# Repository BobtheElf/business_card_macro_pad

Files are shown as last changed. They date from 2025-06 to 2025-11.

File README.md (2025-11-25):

# Business Card Macro Pad
As an electrical engineer, I wanted to design a business card that can also help the people with whom I am networking. This business card doubles as an RP2040 macro pad, which can be programmed to include any custom key bindings. Special thanks to Robert Feranec at FEDEVEL which this board makes heavy modifications to. His playlist where I learned to make this is here: <https://www.youtube.com/playlist?list=PLXvLToQzgzdftro2qK5In8p6ExsDFdpzw>

In addition, this repository includes the Gerber files, BOM, PnP, and 3D shell files to manufacture this board. Firmware exists in the Software directory, where you can use qmk to flash the board and via to program it once it is flashed. This is what it looks like fully built:

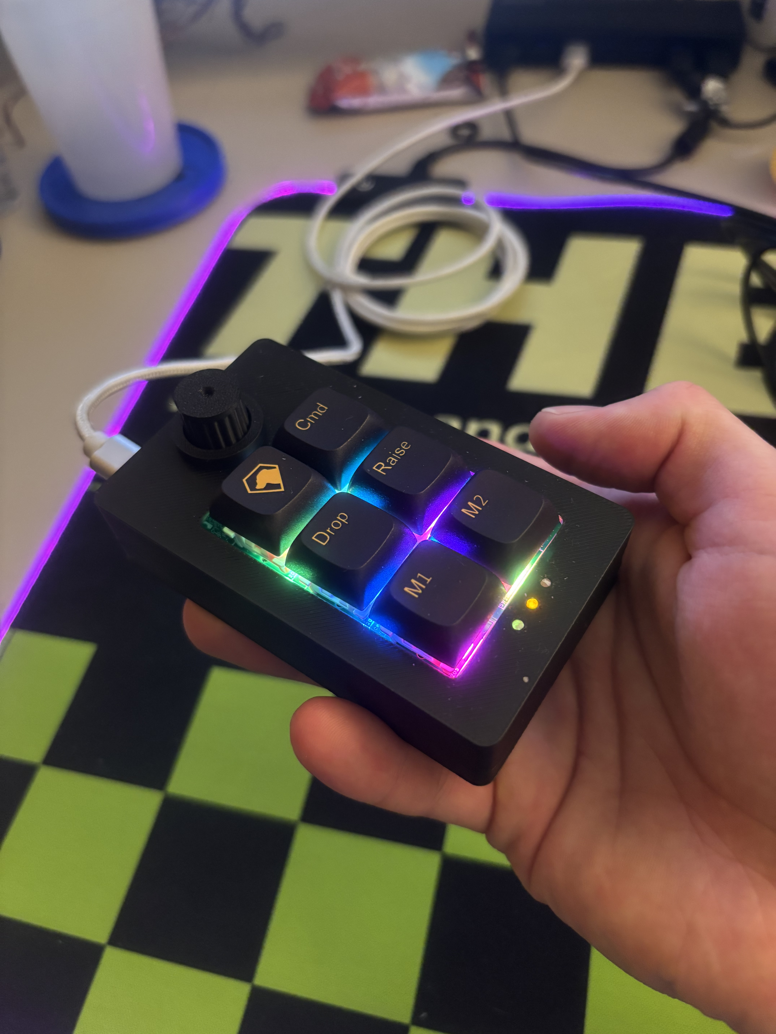
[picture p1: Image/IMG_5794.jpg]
1 encoder, 6 key macro pad with black, 3D printed case and RGB underglow underneath each key switch


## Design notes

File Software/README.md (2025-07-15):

# Software
The two documents you will need to ensure the ability to use Via are the qmk-compiled default firmware ```bcmp.uf2``` as well as the ```via.json``` file which gives Via the correct key mappings and layouts to interface with the qmk-compiled code. Note that Via may be painfully slow or unresponsive when authorizing this keyboard, but if you check the Settings tab or inspect the page or check the console, you can see that these are the correct steps. 
## Flashing the board with default firmware
1. Set the board to bootloader mode. If the board is brand new and unprogrammed, then it will automatically be in bootloader mode upon plugin, however, if there is already code, then press the *BOOT* button as the board is being plugged in. After releasing the *BOOT* button, the board will be in bootloader mode and appear as a drive called ```RPI-RP2```.
2. Copy the ```bcmp.uf2``` file into the ```RPI-RP2``` drive. After this, the board will disconnect as a drive and reappear as a keyboard, complete with the default firmware.
## Programming with Via
1. Visit ```https://usevia.app/``` on your browser.
2. Go to the Settings tab and toggle the "Show Design tab" option on. There should be a new menu option appear, and this is the Design tab.
3. Go to the Design tab and click the option to "Load Draft Definition". Find the ```via.json``` file and load this as the draft definition. The entry "Jaron's Business Card Macro Pad" should appear under the "Draft Definitions" section.
4. Go to the Configure tab and click the "Authorize device +" button. Then authorize "Jaron's Business Card Macro Pad".

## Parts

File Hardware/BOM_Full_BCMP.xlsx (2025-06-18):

No. | Quantity | Comment | Designator | Footprint | Value | Manufacturer Part | Manufacturer | Supplier Part | Supplier | Layer
1 | 5 | 2.2uF | C101,C106,C107,C108,C201 | C0402 | 2.2uF | CL05A225MQ5NSNC | SAMSUNG(三星) | C12530 | LCSC | B
2 | 4 | 1uF | C102,C103,C119,C120 | C0402 | 1uF | CL05A105KA5NQNC | SAMSUNG(三星) | C52923 | LCSC | B
3 | 18 | 100nF | C104,C105,C109,C110,C111,C112,C113,C114,C115,C125,C126,C127,C210,C211,C212,C213,C214,C215 | C0402 | 100nF | CL05B104KO5NNNC | SAMSUNG(三星) | C1525 | LCSC | B
4 | 1 | 47uF | C116 | C1206 | 47uF | CL31A476MPHNNNE | SAMSUNG(三星) | C96123 | LCSC | B
5 | 2 | 15pF | C123,C124 | C0402 | 15pF | CL05C150JB5NNNC | SAMSUNG(三星) | C86285 | LCSC | B
6 | 2 | 10nF | C203,C205 | C0402 | 10nF | CL05B103KB5NNNC | SAMSUNG(三星) | C15195 | LCSC | B
7 | 4 | GG0402052R542P | D101,D102,D103,D104 | D0402-BI |  | GG0402052R542P | Kyocera AVX | C1973257 | LCSC | B
8 | 7 | CD4148WSP | D201,D202,D203,D204,D205,D206,D210 | D0805-RD |  | CD4148WSP | LIZ(丽智电子) | C109001 | LCSC | B
9 | 1 | PEC12R-4120F-S0012 | ENC201 | SW-TH_PEC12R-4120F-S0012 |  | PEC12R-4120F-S0012 | BOURNS | C143801 | LCSC | T
10 | 1 | TYPE-C 16PIN 2MD(073) | J101 | USB-C-SMD_TYPE-C-6PIN-2MD-073 |  | TYPE-C 16PIN 2MD(073) | SHOU HAN(首韩) | C2765186 | LCSC | B
11 | 6 | CPG151101S11-16 | J201,J202,J203,J204,J205,J206 | SMD_KEYBOARD-SW |  | CPG151101S11-16 | Kailh(凯华) | C5156480 | LCSC | B
12 | 1 | NH-B1010RGBT-HF | LED101 | LED-ARRAY-SMD_4P-L1.0-W1.0-TR_NH-B1010RGBT |  | NH-B1010RGBT-HF | 国星光电 | C2874113 | LCSC | T
13 | 1 | KT-0805G | LED102 | LED0805-R-RD |  | KT-0805G | KENTO | C2297 | LCSC | T
14 | 1 | KT-0805Y | LED103 | LED0805-R-RD |  | KT-0805Y | KENTO | C2296 | LCSC | T
15 | 6 | SK6812MINI-E | LED201,LED202,LED203,LED204,LED205,LED206 | LED-SMD_L3.2-W2.8-LS5.9_SK6812MINI-E |  | SK6812MINI-E | 欧思科光电 | C5149201 | LCSC | B
16 | 4 | STANDOFF_M2.5X3.2MM | MH201,MH202,MH203,MH204 | STANDOFF_M2.5X3.5MM_JO_v1.0 |  |  | WURTH ELEKTRONIK | 46AJ4353 | FARNELL | T
17 | 7 | 1kΩ | R101,R102,R103,R104,R105,R121,R124 | R0402 | 1kΩ | 0402WGF1001TCE | UNI-ROYAL(厚声) | C11702 | LCSC | B
18 | 1 | 200Ω | R106 | R0402 | 200Ω | 0402WGF2000TCE | UNI-ROYAL(厚声) | C25087 | LCSC | B
19 | 1 | 100mΩ | R107 | R1206 | 100mΩ | 1206W4F100LT5E | UNI-ROYAL(厚声) | C25334 | LCSC | B
20 | 7 | 27Ω | R108,R109,R110,R111,R112,R118,R125 | R0402 | 27Ω | 0402WGF270JTCE | UNI-ROYAL(厚声) | C25100 | LCSC | B
21 | 2 | 5.1kΩ | R113,R116 | R0402 | 5.1kΩ | 0402WGF5101TCE | UNI-ROYAL(厚声) | C25905 | LCSC | B
22 | 3 | 0Ω | R114,R115,R117 | R0402 | 0Ω | 0402WGF0000TCE | UNI-ROYAL(厚声) | C17168 | LCSC | B
23 | 5 | 10kΩ | R123,R201,R202,R205,R207 | R0402 | 10kΩ | 0402WGF1002TCE | UNI-ROYAL(厚声) | C25744 | LCSC | B
24 | 2 | TS-1187A-B-A-B | SW101,SW102 | SW-SMD_4P-L5.1-W5.1-P3.70-LS6.5-TL_H1.5 |  | TS-1187A-B-A-B | XKB Connectivity(中国星坤) | C318884 | LCSC | B
25 | 6 | CPG151101D213 | SW201,SW202,SW203,SW204,SW205,SW206 | KEY-TH_CPG151101D21X |  | CPG151101D213 | Kailh(凯华) | C400235 | LCSC | T
26 | 1 | RP2040 | U101 | LQFN-56_L7.0-W7.0-P0.4-EP |  | RP2040 | Raspberry Pi(树莓派) | C2040 | LCSC | B
27 | 1 | LM3940IMP-3.3/NOPB | U102 | SOT-223_L6.5-W3.5-P2.30-LS7.0-BR |  | LM3940IMP-3.3/NOPB | TI(德州仪器) | C140319 | LCSC | B
28 | 1 | W25Q128JVSIQ | U103 | SOIC-8_L5.3-W5.3-P1.27-LS8.0-BL |  | W25Q128JVSIQ | WINBOND(华邦) | C97521 | LCSC | B
29 | 1 | SN74LV1T34DBVR | U104 | SOT-23-5_L2.9-W1.6-P0.95-LS2.8-BR |  | SN74LV1T34DBVR | TI(德州仪器) | C100024 | LCSC | B
30 | 1 | ABM8-272-T3 | Y101 | CRYSTAL-SMD_4P-L3.2-W2.5-BL |  | ABM8-272-T3 | ABRACON | C20625731 | LCSC | B

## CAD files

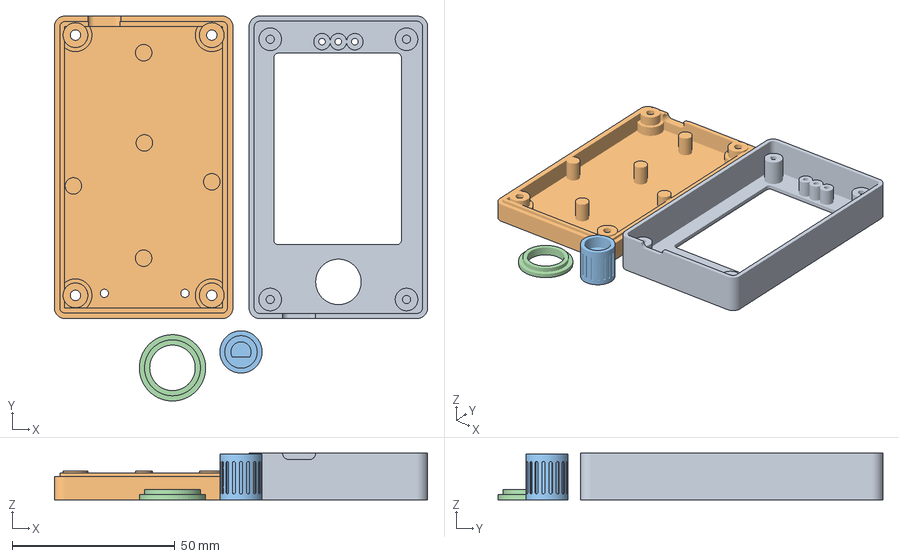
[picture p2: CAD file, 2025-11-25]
Hardware/3DShell_PCB1/Full_Custom_Case.3mf
114.8 x 118.4 x 14.4 mm
3DShell_3DShell_PCB1_T.stl
3DShell_3DShell_PCB1_B.stl
Knob-body-6_2x1_6_normal.stl
ring_print_3x.stl

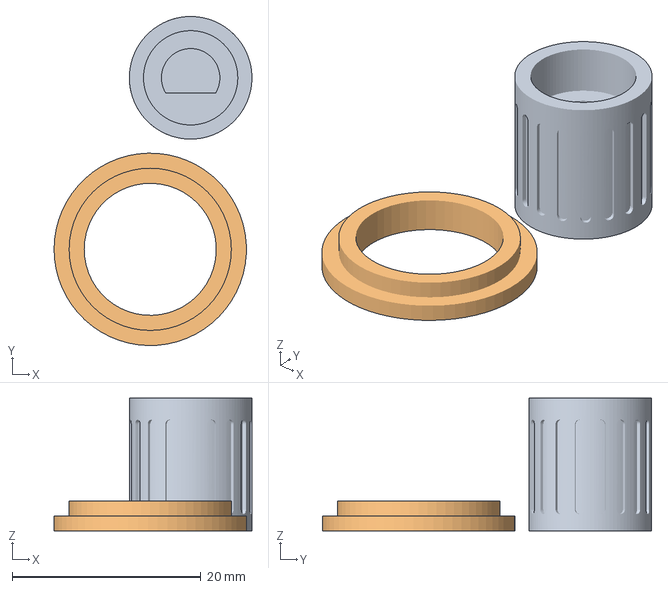
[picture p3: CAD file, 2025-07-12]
Hardware/3DShell_PCB1/knob_and_detailing.3mf
21.0 x 34.9 x 14.1 mm
Knob-body-6_2x1_6_normal.stl
ring_print_3x.stl

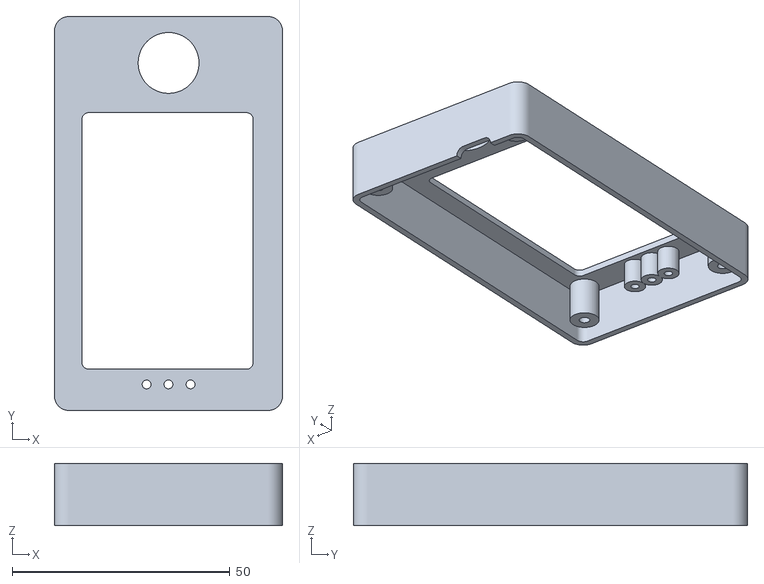
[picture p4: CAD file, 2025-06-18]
Hardware/3DShell_PCB1/Top_Case.stl
52.4 x 90.5 x 14.4

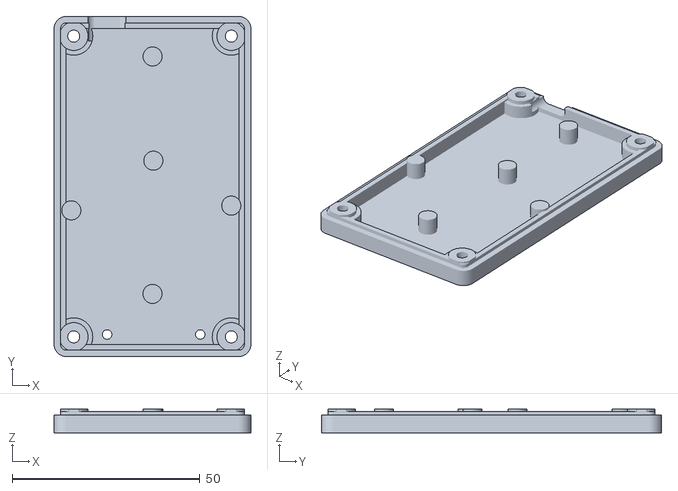
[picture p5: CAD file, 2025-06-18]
Hardware/3DShell_PCB1/Bottom_Case.stl
52.4 x 90.5 x 6.32

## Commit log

2025-06-18 Adding the gerber, bom, pnp, and 3d shell files
    [3DShell_3DShell_PCB1_B.stl, 3DShell_3DShell_PCB1_T.stl, BOM_Full_BCMP.xlsx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]
2025-06-18 Corrected Gerber files
2025-07-12 Software for via
    [knob_and_detailing.3mf]
2025-11-25 Update: 3D files for the case
    [Bottom_Case.stl, Full_Custom_Case.3mf, Top_Case.stl]
